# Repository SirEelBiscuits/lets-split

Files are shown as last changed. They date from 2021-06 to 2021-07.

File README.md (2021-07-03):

# lets-split

a custom remake of the lets split keyboard pcb

PCB designed to match [this case](https://mechboards.co.uk/shop/kits/lets-split-kit/#pcb).

Uses the QMK firmware, my fork of which is here: https://github.com/SirEelBiscuits/qmk_firmware/tree/garnet

As yet, keyboard and keymap are not merged upstream.

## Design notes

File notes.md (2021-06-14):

Notes
=====

Parts
-----

USB jack:
https://www.digikey.co.uk/product-detail/en/gct/USB4085-GF-A/2073-USB4085-GF-ACT-ND/9859733
cost is 1.26GBP/ea

reset button:
https://www.digikey.co.uk/product-detail/en/apem-inc/MJTP1230/679-2428-ND/1798037
`sw_push_6mm_h4.3`

Helpful info
------------

### Other designs

Someone else's build: https://github.com/tzarc/djinn/blob/main/Rev2a/Djinn.pdf
cached here: file:///C:/Users/Jameson/Downloads/Djinn.pdf

Above includes circuitry for electrostatic discharge, and similar

### QMK split keyboard reference

[here](https://docs.qmk.fm/#/feature_split_keyboard)

Sandwich diagram
----------------

```
=========  Plate
 ?         iunno
---------  PCB
 |         standoffs
 |
=========  Base
```

### BOM

Keyswitches
Case
PCB
Diodes
ProMicro
Solder

USB-C to USB-C Cable
M3 screws + standoffs
Resistors: 9.1k, 220
USB-C Jack

screw distances:

X 3 1/8"      79mm
Y 4 5/8"     117mm

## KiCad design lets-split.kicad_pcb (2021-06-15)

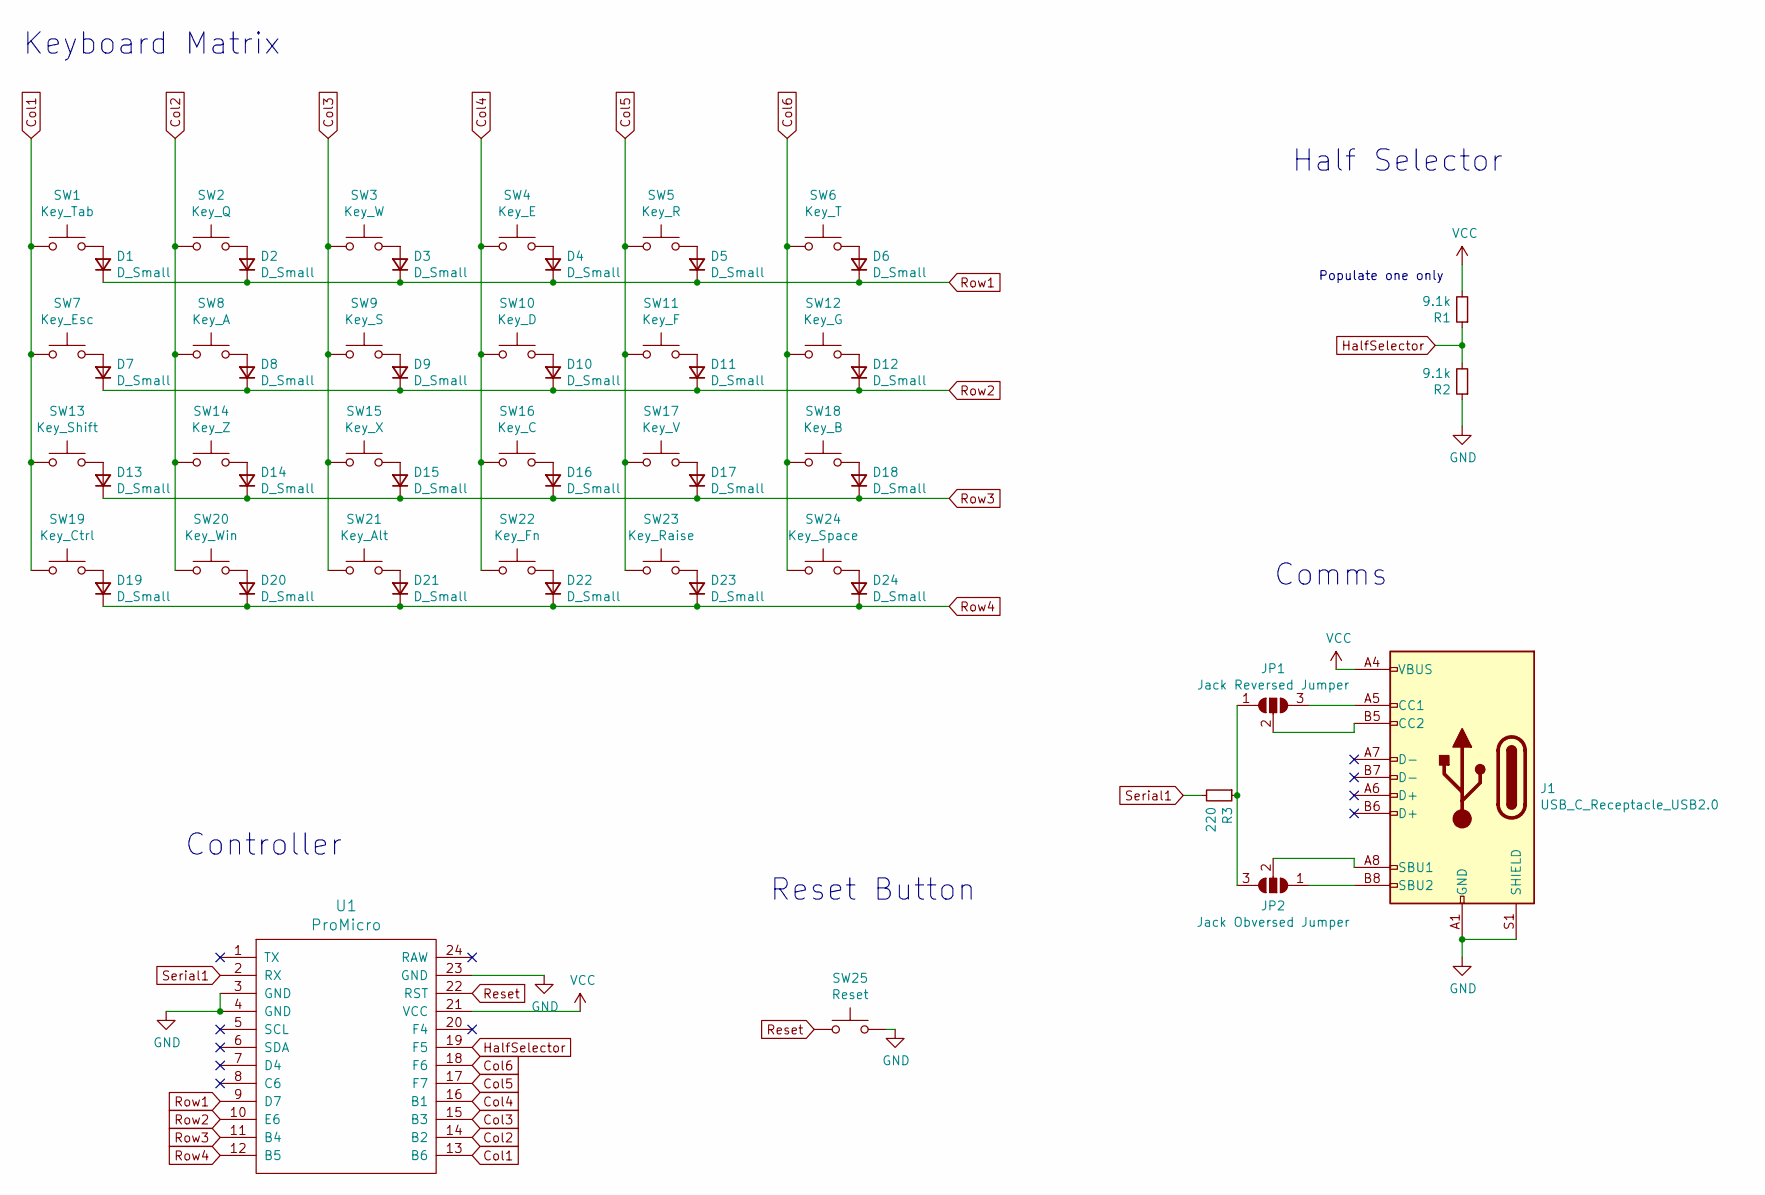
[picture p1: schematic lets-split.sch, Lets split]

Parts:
D1, D2, D3, D4, D5, D6, D7, D8, D9, D10, D11, D12, D13, D14, D15, D16, D17, D18, D19, D20, D21, D22, D23, D24: D_Small; D_DO-35_SOD27_P7.62mm_Horizontal
J1: USB_C_Receptacle_USB2.0; USB_C_GCT_USB4085
JP1: Jack Reversed Jumper; SolderJumper-3_P1.3mm_Open_RoundedPad1.0x1.5mm
JP2: Jack Obversed Jumper; SolderJumper-3_P1.3mm_Open_RoundedPad1.0x1.5mm
R1, R2: 9.1k; R_Axial_DIN0207_L6.3mm_D2.5mm_P7.62mm_Horizontal
R3: 220; R_Axial_DIN0207_L6.3mm_D2.5mm_P7.62mm_Horizontal
SW1: Key_Tab; SW_MX_reversible
SW2: Key_Q; SW_MX_reversible
SW3: Key_W; SW_MX_reversible
SW4: Key_E; SW_MX_reversible
SW5: Key_R; SW_MX_reversible
SW6: Key_T; SW_MX_reversible
SW7: Key_Esc; SW_MX_reversible
SW8: Key_A; SW_MX_reversible
SW9: Key_S; SW_MX_reversible
SW10: Key_D; SW_MX_reversible
SW11: Key_F; SW_MX_reversible
SW12: Key_G; SW_MX_reversible
SW13: Key_Shift; SW_MX_reversible
SW14: Key_Z; SW_MX_reversible
SW15: Key_X; SW_MX_reversible
SW16: Key_C; SW_MX_reversible
SW17: Key_V; SW_MX_reversible
SW18: Key_B; SW_MX_reversible
SW19: Key_Ctrl; SW_MX_reversible
SW20: Key_Win; SW_MX_reversible
SW21: Key_Alt; SW_MX_reversible
SW22: Key_Fn; SW_MX_reversible
SW23: Key_Raise; SW_MX_reversible
SW24: Key_Space; SW_MX_reversible
SW25: Reset; SW_PUSH_6mm_H4.3mm
U1: ProMicro

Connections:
Col1: SW1.1, SW7.1, SW13.1, SW19.1, U1.13 (B6)
Col2: SW2.1, SW8.1, SW14.1, SW20.1, U1.14 (B2)
Col3: SW3.1, SW9.1, SW15.1, SW21.1, U1.15 (B3)
Col4: SW4.1, SW10.1, SW16.1, SW22.1, U1.16 (B1)
Col5: SW5.1, SW11.1, SW17.1, SW23.1, U1.17 (F7)
Col6: SW6.1, SW12.1, SW18.1, SW24.1, U1.18 (F6)
GND: J1.A1 (GND), J1.A12 (GND), J1.B1 (GND), J1.B12 (GND), J1.S1 (SHIELD), R2.1, SW25.2, U1.3 (GND), U1.4 (GND), U1.23 (GND)
HalfSelector: R1.1, R2.2, U1.19 (F5)
unnamed: D1.2 (A), SW1.2
unnamed: D2.2 (A), SW2.2
unnamed: D3.2 (A), SW3.2
unnamed: D4.2 (A), SW4.2
unnamed: D5.2 (A), SW5.2
unnamed: D6.2 (A), SW6.2
unnamed: D7.2 (A), SW7.2
unnamed: D8.2 (A), SW8.2
unnamed: D9.2 (A), SW9.2
unnamed: D10.2 (A), SW10.2
unnamed: D11.2 (A), SW11.2
unnamed: D12.2 (A), SW12.2
unnamed: D13.2 (A), SW13.2
unnamed: D14.2 (A), SW14.2
unnamed: D15.2 (A), SW15.2
unnamed: D16.2 (A), SW16.2
unnamed: D17.2 (A), SW17.2
unnamed: D18.2 (A), SW18.2
unnamed: D19.2 (A), SW19.2
unnamed: D20.2 (A), SW20.2
unnamed: D21.2 (A), SW21.2
unnamed: D22.2 (A), SW22.2
unnamed: D23.2 (A), SW23.2
unnamed: D24.2 (A), SW24.2
unnamed: J1.A5 (CC1), JP1.3 (B)
unnamed: J1.A8 (SBU1), JP2.2 (C)
unnamed: J1.B5 (CC2), JP1.2 (C)
unnamed: J1.B8 (SBU2), JP2.1 (A)
unnamed: JP1.1 (A), JP2.3 (B), R3.1
Reset: SW25.1, U1.22 (RST)
Row1: D1.1 (K), D2.1 (K), D3.1 (K), D4.1 (K), D5.1 (K), D6.1 (K), U1.9 (D7)
Row2: D7.1 (K), D8.1 (K), D9.1 (K), D10.1 (K), D11.1 (K), D12.1 (K), U1.10 (E6)
Row3: D13.1 (K), D14.1 (K), D15.1 (K), D16.1 (K), D17.1 (K), D18.1 (K), U1.11 (B4)
Row4: D19.1 (K), D20.1 (K), D21.1 (K), D22.1 (K), D23.1 (K), D24.1 (K), U1.12 (B5)
Serial1: R3.2, U1.2 (RX)
VCC: J1.A4 (VBUS), J1.A9 (VBUS), J1.B4 (VBUS), J1.B9 (VBUS), R1.2, U1.21 (VCC)

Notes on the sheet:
Populate one only
Keyboard Matrix
Controller
Half Selector
Comms
Reset Button

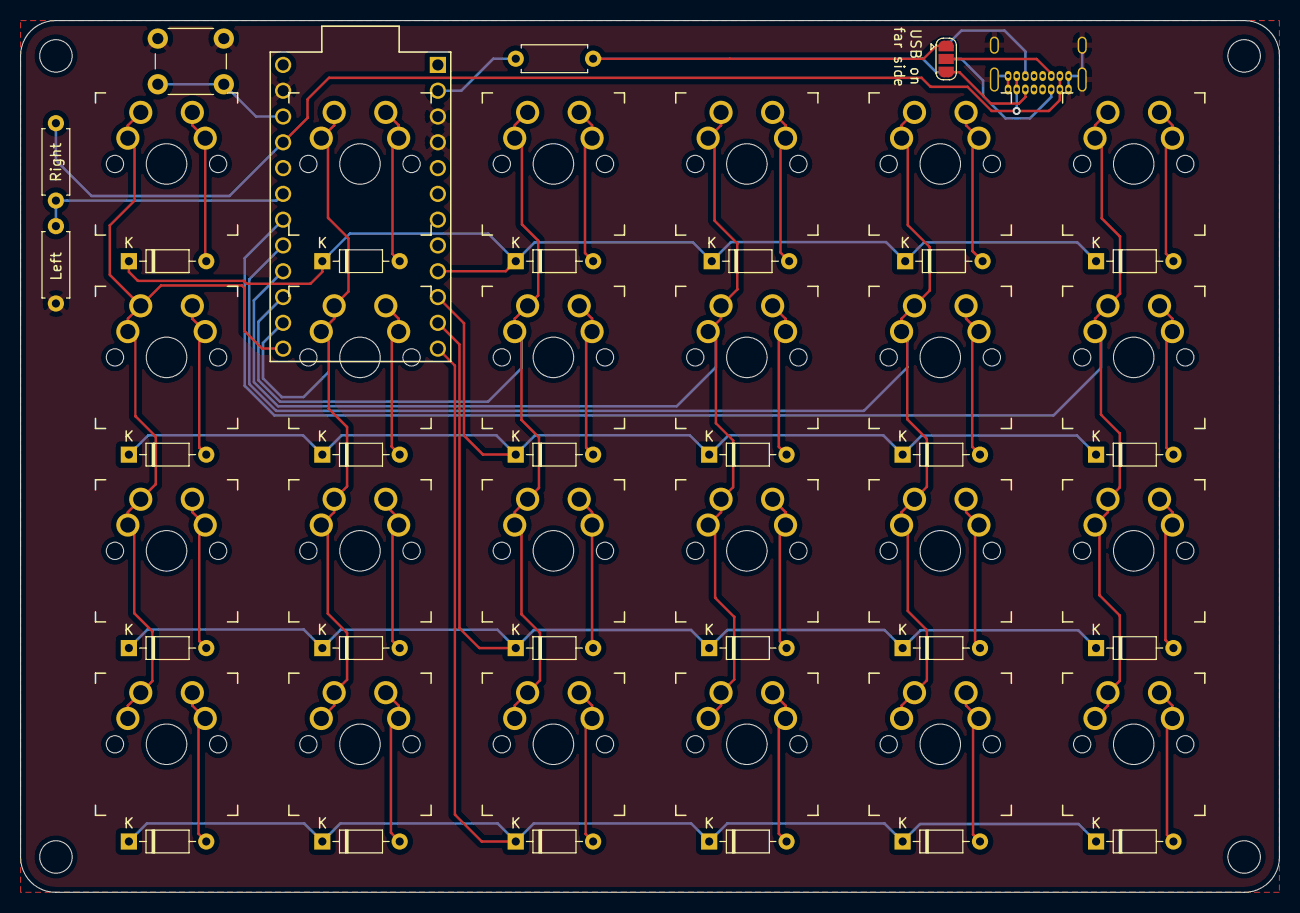
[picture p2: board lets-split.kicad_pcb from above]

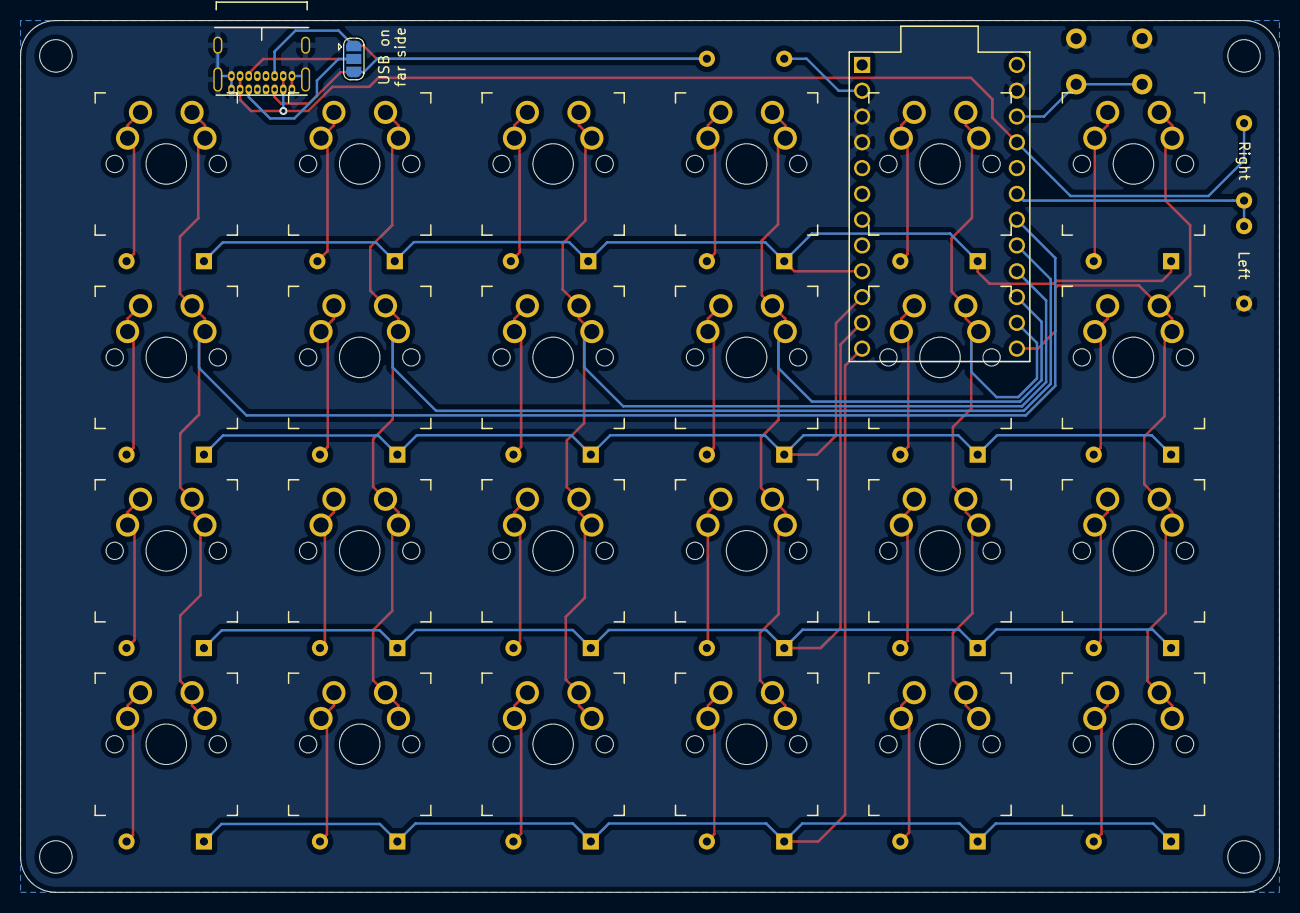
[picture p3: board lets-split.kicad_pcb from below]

Board: 2 copper layers, 124.0 x 85.9 mm, 56 parts (3 on the bottom side), 44 nets.

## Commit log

2021-06-12 kicad gitignore
2021-06-12 rev 1 of schematic started.
    All Keys
    TRRS
    Reset switch
    handedness jumper
    [lets-split.sch]
2021-06-12 added annotations
    [lets-split.sch]
2021-06-12 Assigned footprints to most components
    [lets-split.sch]
2021-06-12 Switched TRRS to USB-C abuse. Should be safer.
    Also added resistor on data pins
    And replaced hand selector jumper with a pull up/down resistor (lower
    power I guess?)
    [lets-split.sch]
2021-06-12 Corrected footprint associations
    [lets-split.sch]
2021-06-13 corrected reset button footprint
    [lets-split.sch]
2021-06-13 Created PCB file, positioned parts
    [lets-split.kicad_pcb]
2021-06-13 Fixed USB-C connector not passing inspection.
    Added jumper to allow it to be mounted on either side of the board
    [lets-split.kicad_pcb, lets-split.sch]
2021-06-13 PCB traces laid. Fixed labels on columns on schematic.
    [lets-split.kicad_pcb, lets-split.sch]
2021-06-13 corrected reset button to go to gnd
    [lets-split.kicad_pcb, lets-split.sch]
2021-06-13 Added ground planes
    [lets-split.kicad_pcb]
2021-06-14 added screw holes, tweaked board edge positions
    [lets-split.kicad_pcb]
2021-06-14 Incorporated Kliment's feedback
    Moved traces apart from everything
    Removed one via
    moved vias from under USB connector
    Rounded corners
    [lets-split.kicad_pcb]
2021-06-14 added labels for jumpers and resistors
    [lets-split.kicad_pcb]
2021-06-14 Reversed column pin order to tidy PCB
    [lets-split.kicad_pcb, lets-split.sch]
2021-06-15 Revised board
    Moved controller over 1 column
    moved usb-c to top edge
    simplified routing overall
    now only 1 via, and absolute minimum number of traces under the USB jack
    (one each side!)
    [lets-split.kicad_pcb]

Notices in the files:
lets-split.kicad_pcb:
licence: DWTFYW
